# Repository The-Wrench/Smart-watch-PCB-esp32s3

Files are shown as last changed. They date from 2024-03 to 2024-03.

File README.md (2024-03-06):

# Smart-watch-PCB-esp32s3

This Project was made to show of my Electronic and IT skills.

### Content list

1. a
2. b
3. c

###

## The Story behind the Project

The Story behind the Project is relatively simple. I was Scrolling through Pinterest and looking at some DIY Smartwatches.
Pinterest then suggested to me a Hackaday article about Retro LED Segment-displays/Matrix-displays, in which i immeadetly found interest.
One of the listed Displays did catch my Eye, the HDSP-2000 Series Alphanumeric Matrix Display in DIP-Package format made by HP.
In that moment i knew i needed one of these Chips just to play around, perhaps even use in an actual Project; This is that Project.
So i Started to Design my ESP32s3 based smartwatch which would use the HDSP-2000 as the Display.

## Goals for this Project:

- [x]  Design a RTC/c Circuit
- [x]  Design the HDSP-2000 Driver Circuit
- [x]  Add a Buzzer
- [x]  Add an IO expander
- [x]  Add Testpads
- [ ]  SMD Solder the PCB
- [ ]  Test the PCB ==without== the Displays to verify the Driver Circuit
- [ ]  Test the PCB ==with== the Displays
- [ ]  SUCCESS! 🎉

## Quick start guide

1. Order the PCB from JLCPCB or PCBWAY (not sponsored)
2. Solder the componenets onto the board (i recommend the [SAND TECHNIQUE](https://youtu.be/DYrucIWig24?si=pEKrY5gaIevp7irn&t=319))
3. Test the PCB for connection errors or Shorts
4. insert your favorite colored HDSP-2000 series display (or other [Compatible models]())
5. Flash the Firmware [download here]().
6. Download the App [from here]().
7. SUCCESS! 🎉

## The License

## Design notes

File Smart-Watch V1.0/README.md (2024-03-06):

# Smartwatch-ESP32s3

## Order files

  Here you will find all Files necessary to Order the PCB from your PCB-Manufacturer of choice.
  i do recommend using either JLCPCB or PCBWAY due to the cost effectiveness and the relatively easy ordering process
  i will also provide instructions as to how to order from them. (with pictures)

## Pictures

  Here you will find Pictures documenting my Progress as well as some other Pictures.

##  Project Files

  here you will find all necassary Files to edit the PCB and Schematics.
  i also included various converted version of the schematic and PCB for use in other CAD software.

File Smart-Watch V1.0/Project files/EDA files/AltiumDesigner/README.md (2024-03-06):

i dont support closed source/ignorant corporations that charge by month for a software that should be a one time payment.

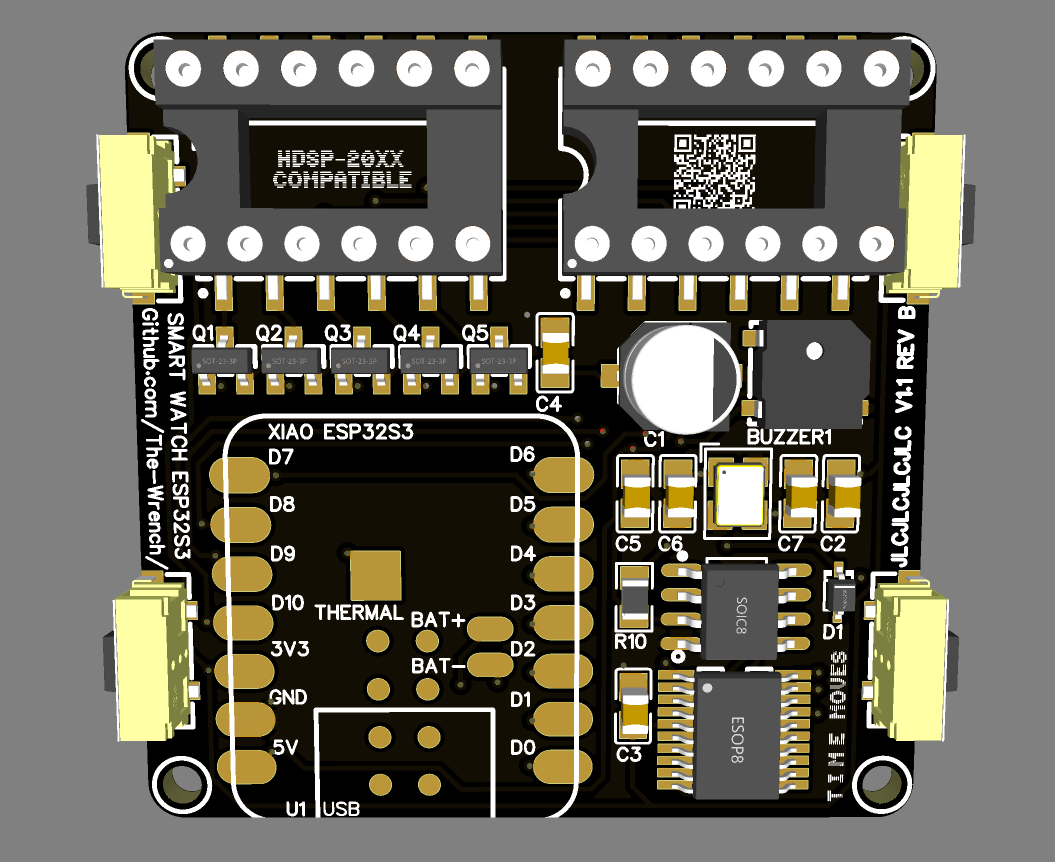
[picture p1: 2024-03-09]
Smart-Watch V1.0/Pictures/pcb_pic.PNG

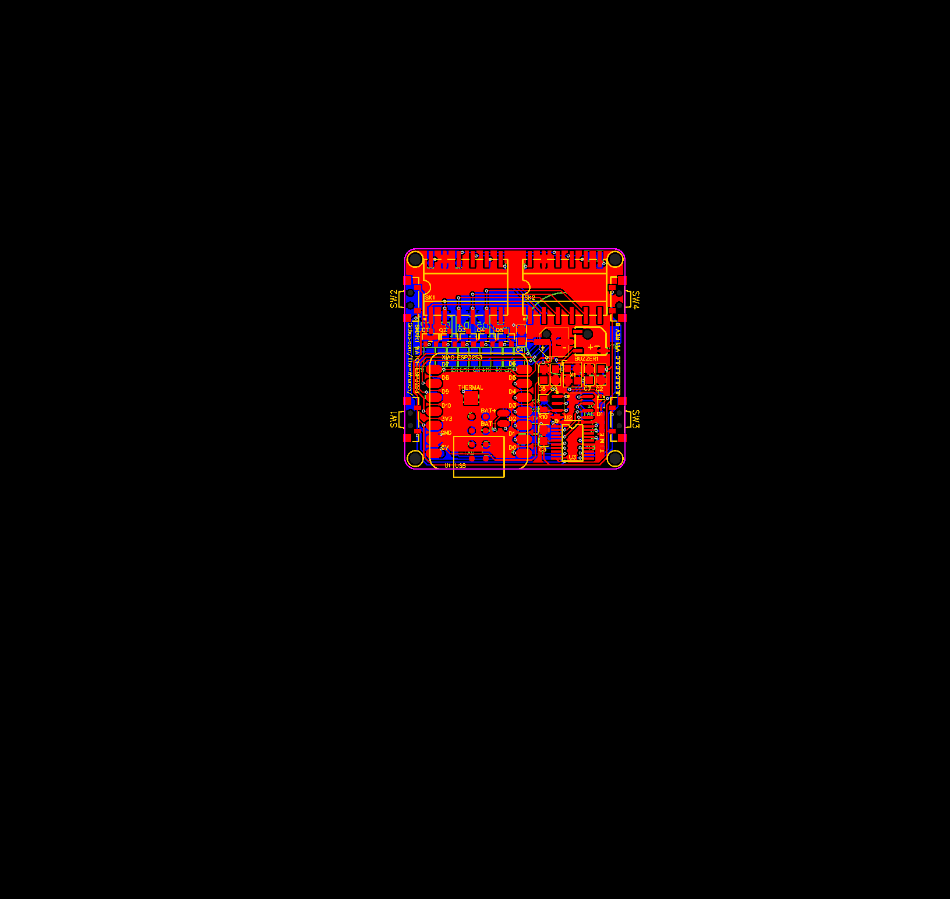
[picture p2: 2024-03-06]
Smart-Watch V1.0/Pictures/PCB_PCB_wristwatch-v1.1_2024-02-29(1).png

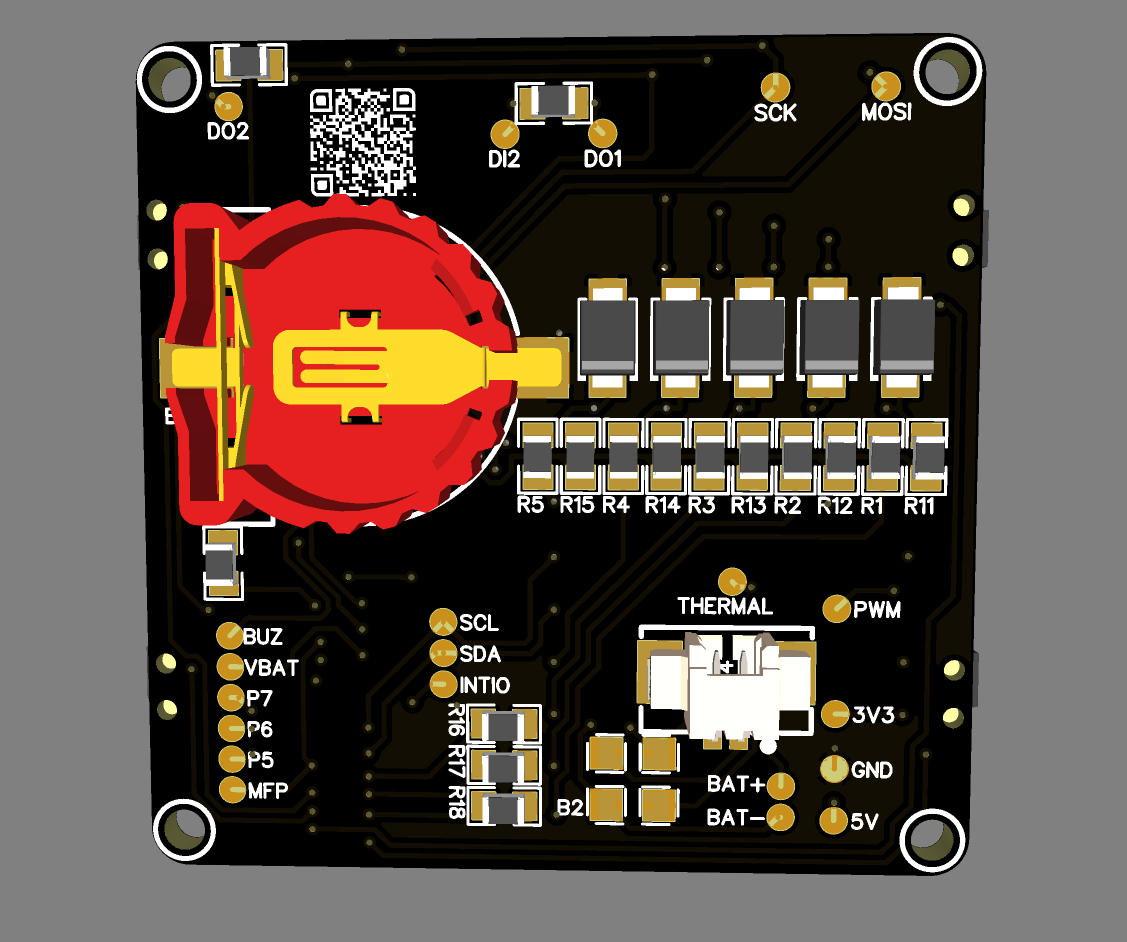
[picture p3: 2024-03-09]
Smart-Watch V1.0/Pictures/pcb_pic2.PNG

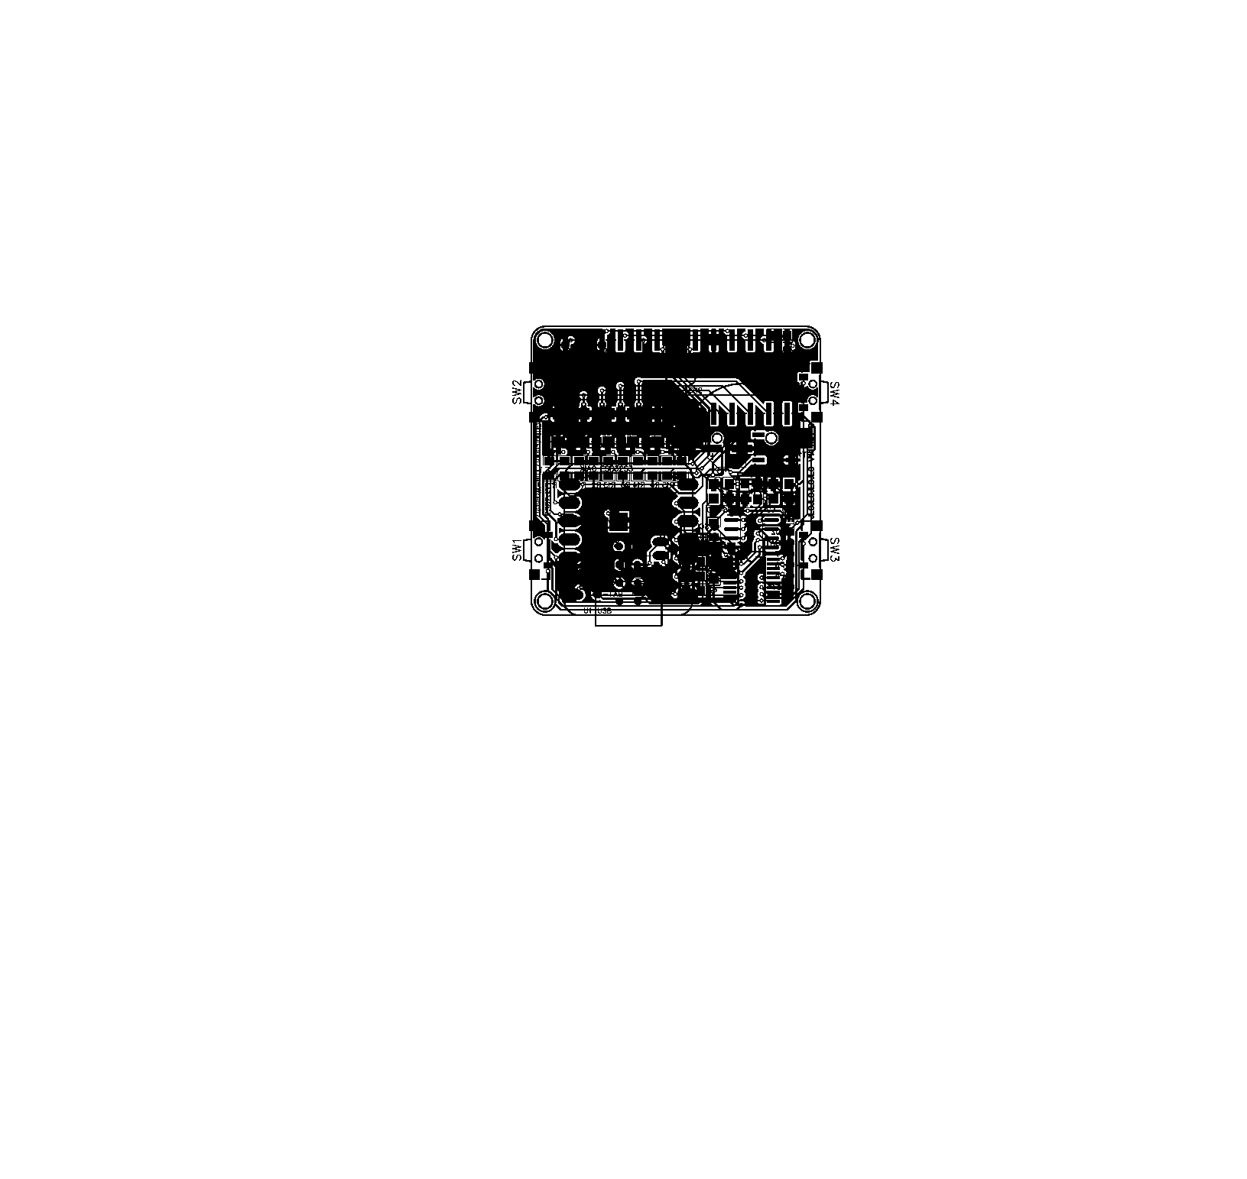
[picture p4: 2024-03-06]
Smart-Watch V1.0/Pictures/PCB_PCB_wristwatch-v1.1_2024-02-29.png

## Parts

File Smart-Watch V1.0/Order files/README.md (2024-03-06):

# PCB Order Files

## Content

## How to order from JLCPCB

  1. Download the Current Order files from [here]()
  2. DO NOT unzip the Gerber.zip!
  3. go to [JLCPCBs website](https://jlcpcb.com/)
  4. Click on INSTANT QUOTE
  5. drag your Downloaded Gerber.zip to the Field ADD GERBER FILE
  6. Select "FR-4" as the Base Material
  7. Select "2" Layers
  8. Check that the Dimensions are correct (should automaticly be Filled out)
  9. Select your Desired PCB quantity
  10. Select "Industrial/consumer electronics" as the Product type
  11. Select "Single PCB" as the Delivery format (unless you would rather have JLCPCB make it a Panel for you in that case Select "Panel by JLCPCB")
  12. Select PCB Thickness "1.6"
  13. Select your Desired PCB Color (i really like Black and Purple)
  14. Select "Leadfree HASL" or "ENIG" as your surface finish (i do not recommend the normal HASL option because it contains Lead and Lead is Carcinogenic)
  15. Select "Untented" Via Coverings
  16. Select "Specify a location" as your option for "Remove Order Number"
  17. (optionally) you may also Order a Stencil to make assembly easier if you are going to Solder the Components yourself OR
  18. (optionally) you may also Select "PCB Assembly" which will let JLCPCB know to put most of the components onto the board for you (they dont have all the Components in Stock)
  19. (PCB Assembly) TO BE ADDED SOON!

## How to order from PCBWAY

  1. Download the Current Order files from [here]()
  2. DO NOT unzip the Gerber.zip!
  3. go to [PCBWAYs website](https://www.pcbway.com/)
  4. Click on QUOTE NOW
  5. Click on QUICK ORDER PCB
  6. drag your Downloaded Gerber.zip to the Field ADD GERBER FILE
  7. Select "Single PCB" as the Board type (unless you would rather have PCBWAY make it a Panel for you in that case Select "Panel by PCBWAY")
  8. Check that the Dimensions are correct (should automaticly be Filled out)
  9. Select your Desired PCB quantity
  10. Select "2" Layers
  11. Select "FR-4" as the Base Material
  12. Select "TG 150-160" for the option FR4-TG
  14. Select Thickness "1.6"
  15. Select "6/6mil" as min. Track/Spacing
  16. Select "0.2" as min. Hole size
  17. Select your Desired PCB Color/Solder mask (i really like Black and Purple)
  18. Select "Leadfree HASL" or "ENIG" as your surface finish (i do not recommend the normal HASL option because it contains Lead and Lead is Carcinogenic)
  20. Select "yes" as your option for "Remove Product Number"
  21. (optionally) you may also Order a Stencil to make assembly easier if you are going to Solder the Components yourself
  22. Select "non-framework" as Stencil type
  23. Select "190x290mm" as Stencil Size
  24. Select "Top+Bottom (single Stencil)" as Stencil Side
  25. (optionally) you may also Select "PCB Assembly" which will let PCBWAY know to put most of the components onto the board for you (they dont have all the Components in Stock)
  26. (PCB Assembly) TO BE ADDED SOON!

## Requirements for other PCB manufacturers

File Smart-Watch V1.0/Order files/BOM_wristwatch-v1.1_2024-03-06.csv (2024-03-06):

ID | Name | Designator | Footprint | Quantity | Manufacturer Part | Manufacturer | Supplier | Supplier Part | Price | Pins | 3DModel | Contributor | JLCPCB Part Class | link
1 | 1SMAF4733A | D3,D4,D5,D6,D2 | SMAF_L3.5-W2.6-LS4.7-RD | 5 | 1SMAF4733A | SHIKUES(时科) | LCSC | C111632 | 0.022 | 2 | SMAF_L3.5-W2.6-LS4.7-RD-1 | lcsc | Extended Part | https://item.szlcsc.com/125168.html
2 | BS-12-B3AA009 | BT1 | BAT-SMD_BS-12-B3AA011 | 1 | BS-12-B3AA009 | MYOUNG(美阳) | LCSC | C964727 | 0.251 | 2 | BAT-SMD_BS-12-B3AA011 | LCSC | Extended Part | https://item.szlcsc.com/1049695.html?ref=editor&logined=true
3 | TESTPAD | 3V3,5V,BAT+,BAT-,BUZ,DI2,DO1,DO2,GND,INTIO,MFP,MOSI,P5,P6,P7,PWM,SCK,SCL,SDA,VBAT | TESTPAD | 20 |  |  |  |  |  | 1 |  | Berker Canatar
4 | TP | THERMAL | TESTPAD | 1 |  |  |  |  |  | 1 |  | Berker Canatar
5 | UART_RX/TX_Poka-yoke | B2 | UART_RX/TX_POKAYOKE | 1 |  |  |  |  |  | 4 |  | berranremzi
6 | 470Ω | R1,R2,R3,R4,R5 | R0805 | 5 | RT0805BRD07470RL | YAGEO(国巨) | LCSC | C865512 | 0.035 | 2 | R0805_L2.0-W1.3-H0.6 | lcsc | Extended Part | https://item.szlcsc.com/142685.html
7 | 0Ω | R6,R7,R9,R16,R17,R18 | R0805 | 6 | PT0805-R-070RL | YAGEO(国巨) | LCSC | C1882631 | 0.026 | 2 | R0805_L2.0-W1.3-H0.6 | lcsc | Extended Part | https://item.szlcsc.com/142685.html
8 | 10kΩ | R11,R12,R13,R14,R15 | R0805 | 5 | RNCF0805DTE10K0 | SEI(Stackpole Electronics Inc.) | LCSC | C346587 | 0.047 | 2 | R0805_L2.0-W1.3-H0.6 | LCSC | Extended Part | https://item.szlcsc.com/142685.html
9 | YTC-A1251-02ABW | U4 | CONN-SMD_2P-P1.25_YTC-A1251-02ABW | 1 | YTC-A1251-02ABW | YIYUAN(怡远) | LCSC | C7436575 | 0.021 | 4 | CONN-SMD_2P-P1.25_YTC-A1251-02ABW | lcsc | Extended Part | https://atta.szlcsc.com/upload/public/pdf/source/20230703/1435987A1D1278BD8E0276EA6FE76C2F.pdf
10 | 100nF | C4,C2,C3,C5 | C0805 | 4 | CC0805KRX7R9BB104 | YAGEO(国巨) | LCSC | C49678 | 0.005 | 2 | C0805_L2.0-W1.3-H1.3 | lcsc | Basic Part | https://item.szlcsc.com/373011.html
11 | GT-TC054A-H035-L1 | SW1,SW2,SW3,SW4 | SW-SMD_L7.8-W3.5-P4.20-EH | 4 | GT-TC054A-H035-L1 | G-Switch(品赞) | LCSC | C778158 | 0.05 | 4 | SW-SMD_L7.8-W3.5-H3.5-P4.20-EH | LCSC | Extended Part | https://item.szlcsc.com/826760.html?ref=editor&logined=true
12 | 4000Hz | BUZZER1 | BUZ-SMD_L5.0-W5.5-P4.60 | 1 | MLT-5020 | 华能 | LCSC | C94598 | 0.524 | 3 | BUZ-SMD_3P-L5.2-W5.2-H2.0-P3.50 | LCSC | Extended Part | https://item.szlcsc.com/400207.html
13 | 10uF | C1 | CAP-SMD_BD5.0-L5.3-W5.3-FD | 1 | RST10UF50V016 | KNSCHA(科尼盛) | LCSC | C4747971 | 0.025 | 2 | CAP-SMD_BD5.0-L5.3-W5.3-LS5.5-FD | lcsc | Extended Part | https://item.szlcsc.com/245725.html
14 | 10pF | C6 | C0805 | 1 | CL21C100JCANNNC | SAMSUNG(三星) | LCSC | C318752 | 0.011 | 2 | C0805_L2.0-W1.3-H1.3 | LCSC | Extended Part | https://item.szlcsc.com/373011.html
15 | 8.2pF | C7 | C0805 | 1 | 0805CG8R2C500NT | FH(风华) | LCSC | C1840 | 0.005 | 2 | C0805_L2.0-W1.3-H1.3 | lcsc | Extended Part | https://item.szlcsc.com/373011.html
16 | PMEG6002EJ,115 | D1 | SOD-323F_L2.0-W1.6-LS2.5-RD | 1 | PMEG6002EJ,115 | Nexperia(安世) | LCSC | C455059 | 0.095 | 2 | SOD-323F_L1.6-W1.3-H1.1-LS2.7 | LCSC | Extended Part | https://item.szlcsc.com/111628.html
17 | SI2337DS-T1-E3 | Q1,Q2,Q3,Q4,Q5 | SOT-23_L2.9-W1.3-P1.90-LS2.4-BR | 5 | SI2337DS-T1-E3 | VISHAY(威世) | LCSC | C83789 | 0.479 | 3 | SOT-23-3P_L2.9-W1.3-H1.0-LS2.4-P0.95 | LCSC | Extended Part | https://item.szlcsc.com/236142.html
18 | 1kΩ | R10 | R0805 | 1 | ERA6AED102V | PANASONIC(松下) | LCSC | C191555 | 0.053 | 2 | R0805_L2.0-W1.3-H0.6 | LCSC | Extended Part | https://item.szlcsc.com/142685.html
19 | X5621FVS-2X06-C762D1226 | SK1,SK2 | SMD-12_L15.2-W10.2-P2.54-LS12.3-BL | 2 | X5621FVS-2x06-C762D1226 | XKB Connectivity(中国星坤) | LCSC | C2689751 | 0.372 | 12 | SMD-12_L15.2-W10.2-P2.54-LS12.3-BL | LCSC | Extended Part | https://item.szlcsc.com/2797227.html
20 | SEEED XIAO ESP32S3 | U1 | SEEEDUINO XIAO ESP32S3 | 1 | Xiao | Seeeduino | Amazon |  |  | 25 |  | timo6141
21 | MCP79412-I/SN | U2 | SOIC-8_L4.9-W3.9-P1.27-LS6.0-BL | 1 | MCP79412-I/SN | MICROCHIP(美国微芯) | LCSC | C144216 | 1.527 | 8 | SOIC-8_L4.9-W3.9-H1.7-LS6.0-P1.27 | LCSC | Extended Part | https://so.szlcsc.com/global.html?c=&k=C9843
22 | PCF8574APWR | U3 | ETSSOP20_L6.5-W4.4-P0.65-LS6.4-BL | 1 | PCF8574APWR | TI(德州仪器) | LCSC | C94361 | 0.967 | 20 | ETSSOP-20_L6.5-W4.4-H1.2-LS6.4-P0.65 | LCSC | Extended Part | https://list.szlcsc.com/catalog/518.html
23 | 32.768MHz | X1 | CRYSTAL-SMD_4P-L3.2-W2.5-BL-1 | 1 | 7B032768R01 | HD(浩都频率) | LCSC | C655028 | 0.093 | 4 | CRYSTAL-SMD_4P-L3.2-W2.5-BL-1 | LCSC | Extended Part | https://atta.szlcsc.com/upload/public/pdf/source/20180725/C251604_B37BF3660E3A081576A39813BCE4D878.pdf

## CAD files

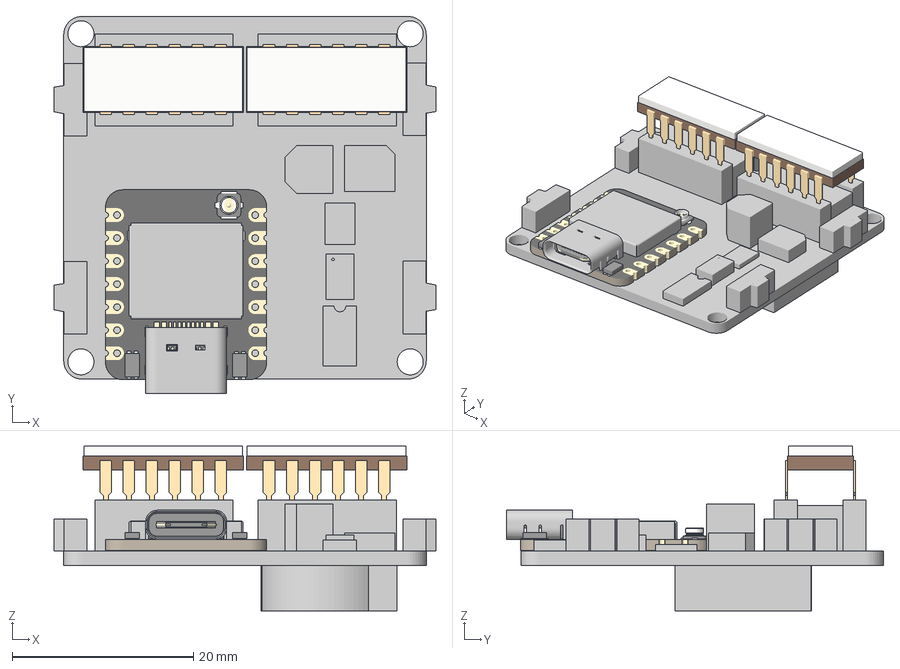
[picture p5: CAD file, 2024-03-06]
Smart-Watch V1.0/Project files/3D Models/STEP model/smartwatch-esp32s3-v1.2 v7.3mf
42.1 x 41.6 x 18.2 mm

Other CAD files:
Smart-Watch V1.0/Project files/3D Models/F3D model/smartwatch-esp32s3-v1.2 v6.f3z

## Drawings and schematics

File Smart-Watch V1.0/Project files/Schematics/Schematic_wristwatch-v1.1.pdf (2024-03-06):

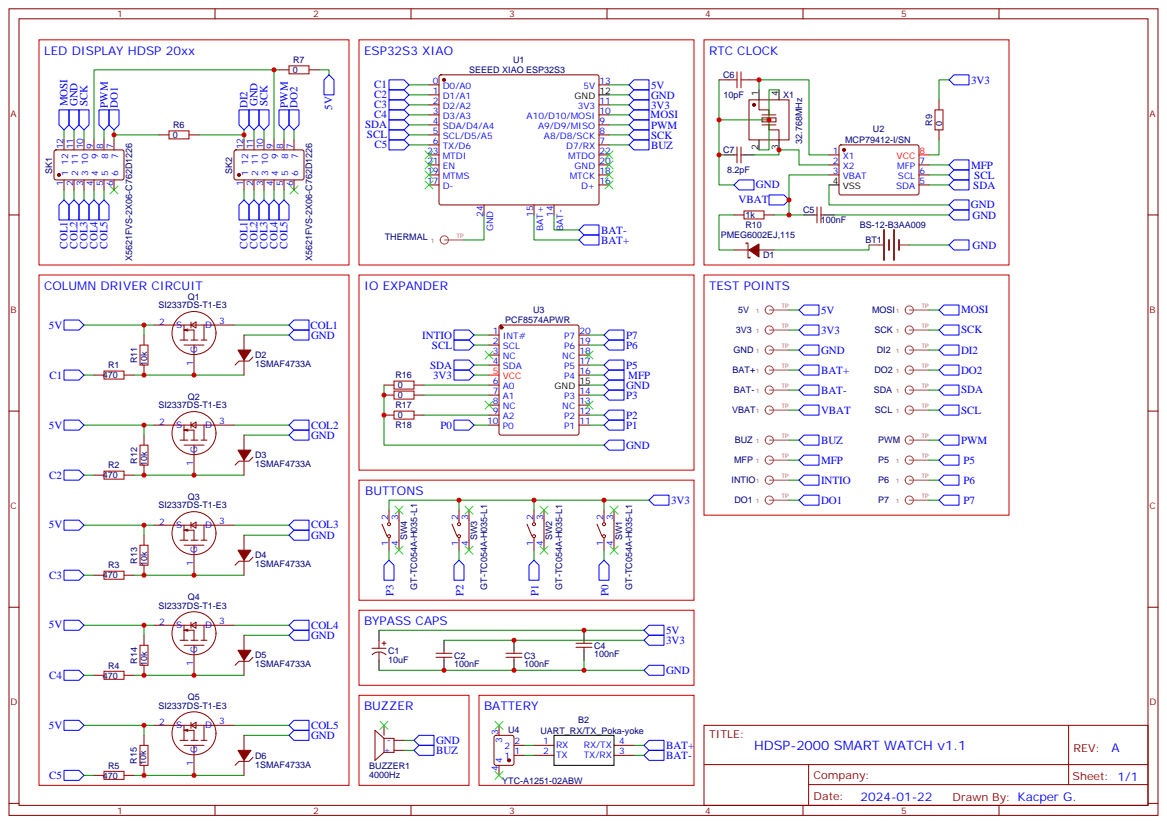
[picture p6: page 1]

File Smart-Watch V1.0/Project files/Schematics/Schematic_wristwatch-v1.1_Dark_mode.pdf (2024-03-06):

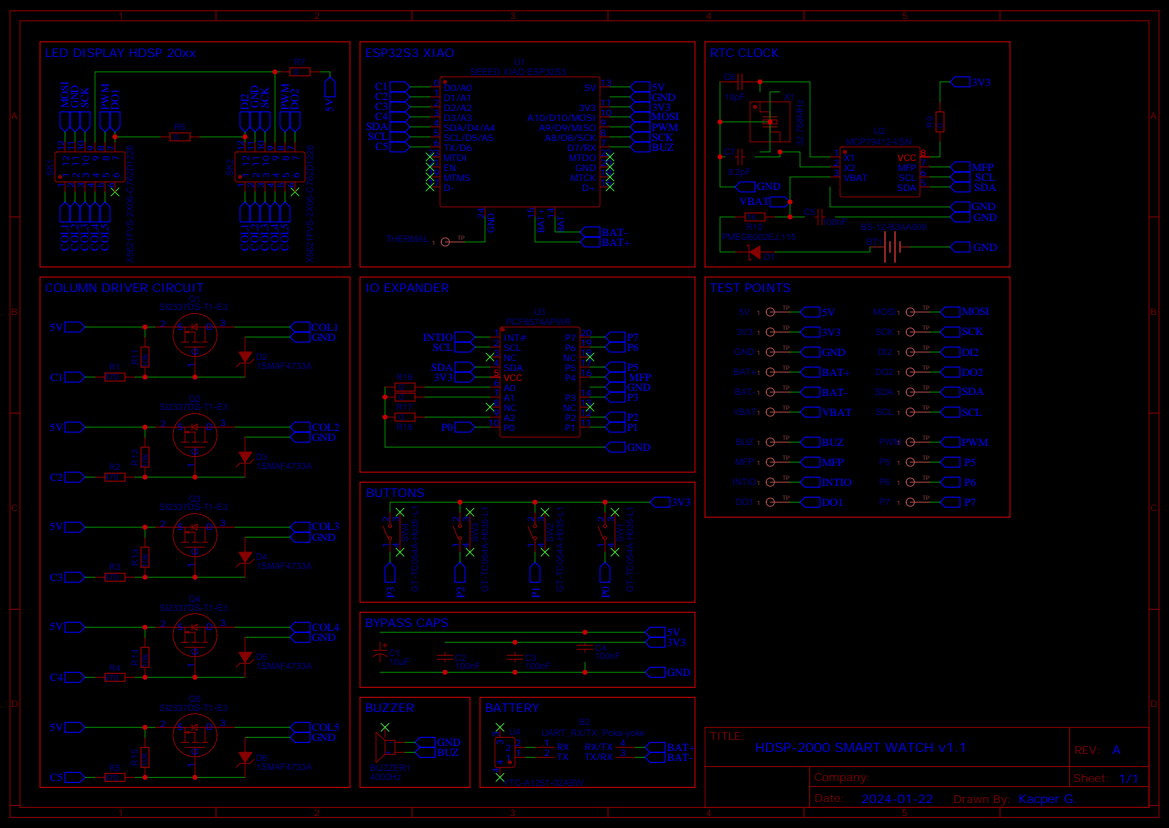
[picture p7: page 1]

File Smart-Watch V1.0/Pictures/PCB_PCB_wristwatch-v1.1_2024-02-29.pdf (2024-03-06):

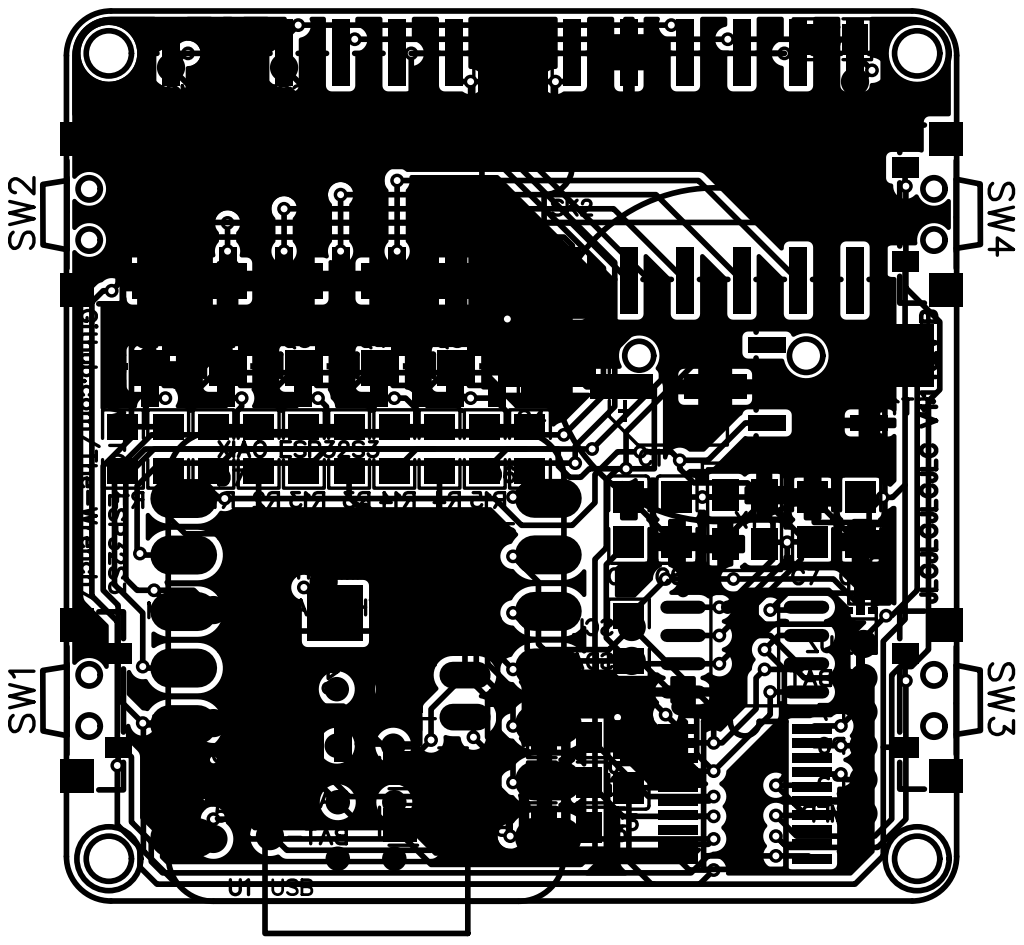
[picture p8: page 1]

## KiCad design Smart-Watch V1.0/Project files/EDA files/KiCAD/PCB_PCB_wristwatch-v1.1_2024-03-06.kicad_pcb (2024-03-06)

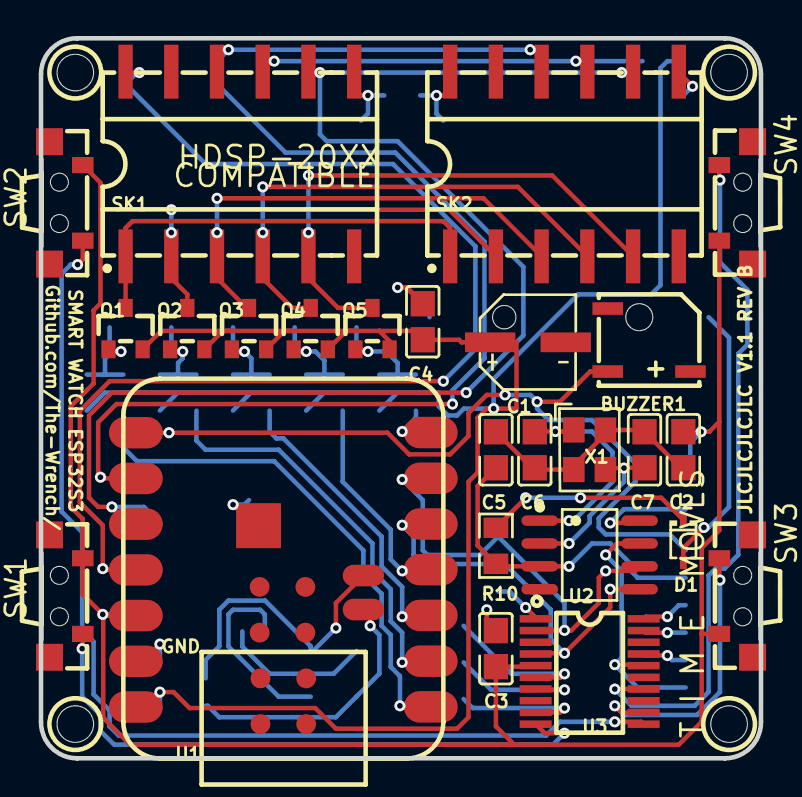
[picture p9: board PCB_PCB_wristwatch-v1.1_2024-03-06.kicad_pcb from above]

Board: 2 copper layers, 40.0 x 40.0 mm, 70 parts (0 on the bottom side), 51 nets.

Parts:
3V3, 5V: TESTPAD
B2: UART_RX/TX_Poka-yoke; UART_RX/TX_POKAYOKE
BAT+: TESTPAD
BAT-: TESTPAD
BT1: BS-12-B3AA009; BAT-SMD_BS-12-B3AA011
BUZ: TESTPAD
BUZZER1: 4000Hz; BUZ-SMD_L5.0-W5.5-P4.60
C1: 10uF; CAP-SMD_BD5.0-L5.3-W5.3-FD
C2, C3, C4, C5: 100nF; C0805
C6: 10pF; C0805
C7: 8.2pF; C0805
D1: PMEG6002EJ,115; SOD-323F_L2.0-W1.6-LS2.5-RD
D2, D3, D4, D5, D6: 1SMAF4733A; SMAF_L3.5-W2.6-LS4.7-RD
DI2: TESTPAD
DO1, DO2: TESTPAD
GND: TESTPAD
INTIO: TESTPAD
MFP: TESTPAD
MOSI: TESTPAD
P5, P6, P7: TESTPAD
PWM: TESTPAD
Q1, Q2, Q3, Q4, Q5: SI2337DS-T1-E3; SOT-23_L2.9-W1.3-P1.90-LS2.4-BR
R1, R2, R3, R4, R5: 470Ω; R0805
R6, R7, R9, R16, R17, R18: 0Ω; R0805
R10: 1kΩ; R0805
R11, R12, R13, R14, R15: 10kΩ; R0805
SCK: TESTPAD
SCL: TESTPAD
SDA: TESTPAD
SK1, SK2: X5621FVS-2X06-C762D1226; SMD-12_L15.2-W10.2-P2.54-LS12.3-BL
SW1, SW2, SW3, SW4: GT-TC054A-H035-L1; SW-SMD_L7.8-W3.5-P4.20-EH
THERMAL: TP; TESTPAD
U1: D-; SEEEDUINO XIAO ESP32S3
U2: MCP79412-I/SN; SOIC-8_L4.9-W3.9-P1.27-LS6.0-BL
U3: PCF8574APWR; ETSSOP20_L6.5-W4.4-P0.65-LS6.4-BL
U4: YTC-A1251-02ABW; CONN-SMD_2P-P1.25_YTC-A1251-02ABW
VBAT: TESTPAD
X1: 32.768MHz; CRYSTAL-SMD_4P-L3.2-W2.5-BL-1

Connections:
3V3: 3V3.TP, C2.2, C3.2, R9.2, SW1.2, SW2.2, SW3.2, SW4.2, U1.11, U3.5
5V: 5V.TP, C1.1, C4.2, Q1.2, Q2.2, Q3.2, Q4.2, Q5.2, R7.2, R11.1, R12.1, R13.1, R14.2, R15.1, U1.13
B2_1: B2.4, U4.2
B2_2: B2.2, U4.1
BAT+: B2.1, BAT+.TP, U1.15
BAT-: B2.3, BAT-.TP, U1.14
BUZ: BUZ.TP, BUZZER1.1, U1.7
C1: R1.1, U1.0
C2: R2.1, U1.1
C3: R3.1, U1.2
C4: R4.2, U1.3
C5: R5.1, U1.6
COL1: Q1.3, SK1.1, SK2.1
COL2: Q2.3, SK1.2, SK2.2
COL3: Q3.3, SK1.3, SK2.3
COL4: Q4.3, SK1.4, SK2.4
COL5: Q5.3, SK1.5, SK2.5
D1_1: D1.1, R10.1
D1_2: BT1.1, D1.2
DI2: DI2.TP, R6.2, SK2.12
DO1: DO1.TP, R6.1, SK1.7
DO2: DO2.TP, SK2.7
GND: BT1.2, BUZZER1.2, C1.2, C2.1, C3.1, C4.1, C5.1, C6.1, C7.1, D2.2, D3.2, D4.2, D5.2, D6.2, GND.TP, R16.1, R17.1, R18.1, SK1.11, SK2.11, U1.12, U2.4, U3.15, X1.2, X1.4
INTIO: INTIO.TP, U3.1
MFP: MFP.TP, U2.7, U3.16
MOSI: MOSI.TP, SK1.12, U1.10
P0: SW1.1, U3.10
P1: SW2.1, U3.11
P2: SW3.1, U3.12
P3: SW4.1, U3.14
P5: P5.TP, U3.17
P6: P6.TP, U3.19
P7: P7.TP, U3.20
PWM: PWM.TP, SK1.8, SK2.8, U1.9
R1_2: D2.1, Q1.1, R1.2, R11.2
R2_2: D3.1, Q2.1, R2.2, R12.2
R3_2: D4.1, Q3.1, R3.2, R13.2
R4_1: D5.1, Q4.1, R4.1, R14.1
R5_2: D6.1, Q5.1, R5.2, R15.2
SCK: SCK.TP, SK1.10, SK2.10, U1.8
SCL: SCL.TP, U1.5, U2.6, U3.2
SDA: SDA.TP, U1.4, U2.5, U3.4
SK1_9: R7.1, SK1.9, SK2.9
U1_24: THERMAL.TP, U1.24
U2_1: C6.2, U2.1, X1.1
U2_2: C7.2, U2.2, X1.3
U2_8: R9.1, U2.8
U3_6: R16.2, U3.6
U3_7: R17.2, U3.7
U3_9: R18.2, U3.9
VBAT: C5.2, R10.2, U2.3, VBAT.TP

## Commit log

2024-01-28 the stuff
    adding most files necessary for pcb ordering
    [BOM_PCB_wristwatch_2024-01-28(1).csv, PickAndPlace_PCB_wristwatch_2024-01-28(1).csv]
2024-01-29 pictures and bom
    pictures and bom
    [BOM_PCB_wristwatch_2024-01-28(1).csv]
2024-02-01 a
    a
    [BOM_PCB_wristwatch_2024-01-28(1).csv, BOM_wristwatch_2024-01-31.csv, PickAndPlace_PCB_wristwatch_2024-01-31.csv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]
2024-02-09 adjusted design for tolerance
    adjusted the design for placement of hdsp-2000 and general small improvements
    [BOM_wristwatch_2024-01-31.csv, BOM_wristwatch_2024-02-09.csv, PickAndPlace_PCB_wristwatch_2024-01-31.csv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]
2024-02-25 changed file structure and included v1.1
    added v1.1
    changed file structure
    [BOM_wristwatch_2024-02-09.csv, PickAndPlace_PCB_wristwatch_2024-02-09.csv]
2024-02-25 more changes to structure
    more changes to structure
    [Smart-Watch-ESP32s3-ENCLOSURE v8.3mf, Smart-Watch-ESP32s3-PCB v6.3mf]
2024-03-06 1.0 "release"
    basicly the 1.0 release but due to me not having built it yet its nor really the finished release
    [BOM_wristwatch-v1.1_2024-03-06.csv, BOM_wristwatch_2024-02-09.csv, PCB_PCB_wristwatch-v1.1_2024-03-06.kicad_pcb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]
2024-03-09 added pcb render pictures
    pcb render
